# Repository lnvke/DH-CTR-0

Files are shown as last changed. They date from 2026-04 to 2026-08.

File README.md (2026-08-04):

# CTR-0
Cheaper Than aRduino is a custom devboard meant to be a cost-effective alternative my choice of the Arduino Nano series of devboard hobbyist microcontrollers. It is based of the same RP2040 microcontroller and will provide similar performance compared to its more costly counterpart, the Arduino Nano V3, which is the board I usually use for projects that require a microcontroller.


=======
## Roadmap
- finalize parts
  -finish footprints for any new parts
- pcb footprint, general size
  - placement/routing first pass
- cost optimization
- routing second pass
- final route optimization
- send gerbers to JLCPCB and order
- assemble
- done

## BOM links:

Capacitors:
0.1 uf https://www.digikey.com/en/products/detail/yageo/CC0402KRX7R7BB104/2103076
4.7 uf https://www.digikey.com/en/products/detail/yageo/CC0402MRX5R5BB475/5195139
10 uf https://www.digikey.com/en/products/detail/yageo/CC0603MRX5R5BB106/2833613
1 uf https://www.digikey.com/en/products/detail/yageo/CC0402KRX5R5BB105/2833744
15 pf https://www.digikey.com/en/products/detail/yageo/CC0402JRNPO9BN150/302751

Resistors:
5.1k https://www.digikey.com/en/products/detail/yageo/RC0402FR-075K1L/726624
27 https://www.digikey.com/en/products/detail/yageo/RC0402FR-0727RL/5280946
10k https://www.digikey.com/en/products/detail/yageo/RC0402FR-0710KL/726523
1k https://www.digikey.com/en/products/detail/yageo/RC0402FR-071KL/726513

Receptacles/Header Pins
THT 20h https://www.digikey.com/en/products/detail/sullins-connector-solutions/PRPC020SAAN-RC/2775234
THT 3h https://www.digikey.com/en/products/detail/sullins-connector-solutions/PRPC003SAAN-RC/2775251
USB4015 https://www.digikey.com/en/products/detail/gct/USB4105-GF-A/11198441

IC
TVS Diode https://www.digikey.com/en/products/detail/texas-instruments/TVS1400DRVR/8566097
NCP1117 https://www.digikey.com/en/products/detail/onsemi/NCP1117ST33T3G/1749063
Flash memory https://www.digikey.com/en/products/detail/macronix/MX25L12872FM2I-10G/10059507
RP2040 https://www.digikey.com/en/products/detail/raspberry-pi/SC0914-13/14306010
Crystal Resonator https://www.digikey.com/en/products/detail/abracon-llc/ABLS-12-000MHZ-B4-T/675654

Interface
SKRKAEE020 Push Button https://www.digikey.com/en/products/detail/alps-alpine/SKRKAEE020/19529176

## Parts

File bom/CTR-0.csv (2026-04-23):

Reference | Qty | Value | DNP | Exclude from BOM | Exclude from Board | Footprint | Datasheet
C1,C2 | 2 | 10u |  |  |  | Capacitor_SMD:C_0603_1608Metric
C3,C4 | 2 | 15p |  |  |  | Capacitor_SMD:C_0402_1005Metric
C5 | 1 | 5u |  |  |  | Capacitor_SMD:C_0402_1005Metric
C6,C15 | 2 | 1u |  |  |  | Capacitor_SMD:C_0402_1005Metric
C7,C8,C9,C10,C11,C12,C13,C14,C16,C17 | 10 | 0.1u |  |  |  | Capacitor_SMD:C_0402_1005Metric
C18 | 1 | 100n |  |  |  | Capacitor_SMD:C_0402_1005Metric
J1 | 1 | USB_C_Receptacle_USB2.0_14P |  |  |  | Connector_USB:USB_C_Receptacle_HRO_TYPE-C-31-M-12 | https://www.usb.org/sites/default/files/documents/usb_type-c.zip
J2,J3 | 2 | Conn_01x20 |  |  |  | Connector_PinHeader_2.54mm:PinHeader_1x20_P2.54mm_Vertical
J4 | 1 | Conn_01x03 |  |  |  | Connector_PinHeader_2.54mm:PinHeader_1x03_P2.54mm_Vertical
R1,R2 | 2 | 5.1k |  |  |  | Resistor_SMD:R_0402_1005Metric
R3,R7,R9 | 3 | 1k |  |  |  | Resistor_SMD:R_0402_1005Metric
R4,R5 | 2 | 27 |  |  |  | Resistor_SMD:R_0402_1005Metric
R6,R8 | 2 | 10k |  |  |  | Resistor_SMD:R_0402_1005Metric
SW1,SW2 | 2 | SW_Push |  |  |  | Button_Switch_SMD:SW_Push_SPST_NO_Alps_SKRK
U1 | 1 | RP2040 |  |  |  | Package_DFN_QFN:QFN-56-1EP_7x7mm_P0.4mm_EP3.2x3.2mm | https://datasheets.raspberrypi.com/rp2040/rp2040-datasheet.pdf
U2 | 1 | NCP1117-3.3_SOT223 |  |  |  | Package_TO_SOT_SMD:SOT-223-3_TabPin2 | http://www.onsemi.com/pub_link/Collateral/NCP1117-D.PDF
U3 | 1 | W25Q128JVS |  |  |  | Package_SO:SOIC-8_5.3x5.3mm_P1.27mm | https://www.winbond.com/resource-files/w25q128jv_dtr%20revc%2003272018%20plus.pdf
U4 | 1 | TVS1400DRV |  |  |  | Package_SON:WSON-6-1EP_2x2mm_P0.65mm_EP1x1.6mm | http://www.ti.com/lit/ds/symlink/tvs1400.pdf
Y1 | 1 | 12MHz |  |  |  | Crystal:Crystal_SMD_3225-4Pin_3.2x2.5mm

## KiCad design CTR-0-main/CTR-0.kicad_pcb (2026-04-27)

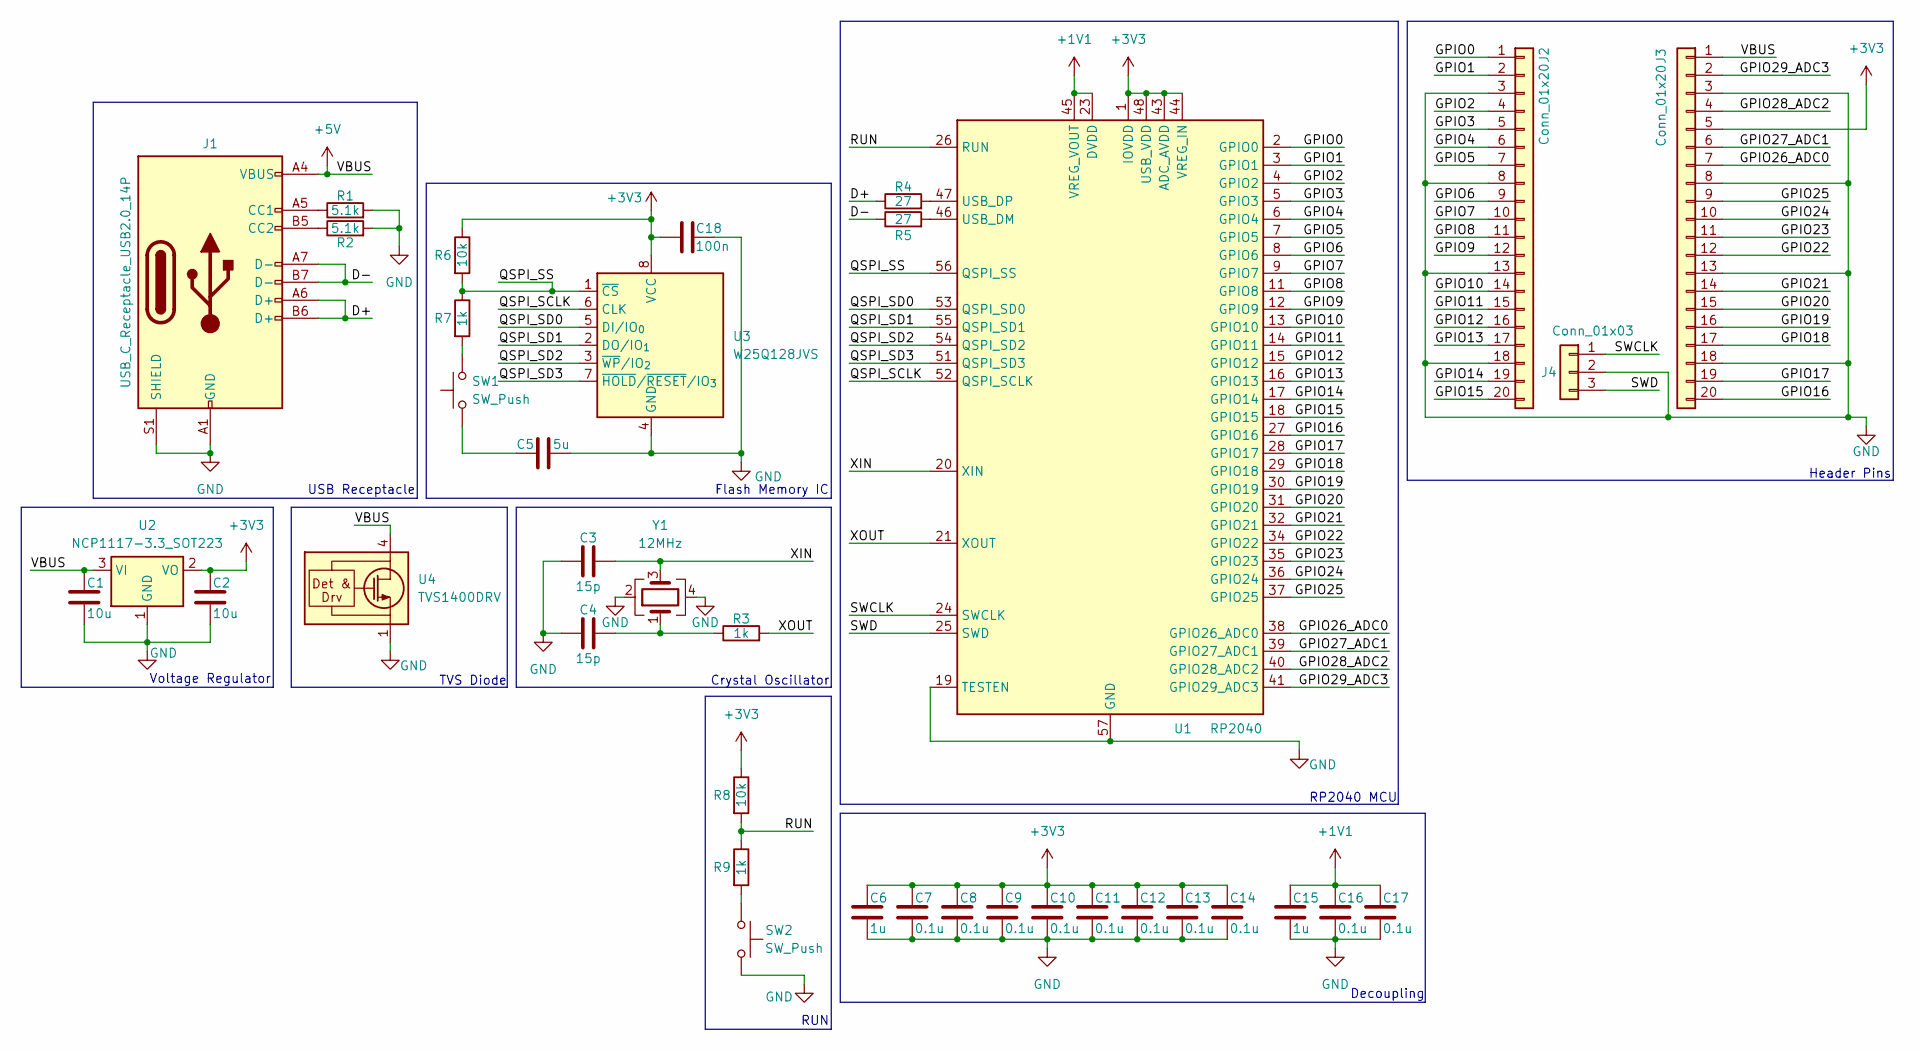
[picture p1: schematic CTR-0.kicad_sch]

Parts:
C1, C2: 10u; C_0603_1608Metric
C3, C4: 15p; C_0402_1005Metric
C5: 5u; C_0402_1005Metric
C6, C15: 1u; C_0402_1005Metric
C7, C8, C9, C10, C11, C12, C13, C14, C16, C17: 0.1u; C_0402_1005Metric
C18: 100n; C_0402_1005Metric
J1: USB_C_Receptacle_USB2.0_14P; USB_C_Receptacle_HRO_TYPE-C-31-M-12
J2, J3: Conn_01x20; PinHeader_1x20_P2.54mm_Vertical
J4: Conn_01x03; PinHeader_1x03_P2.54mm_Vertical
R1, R2: 5.1k; R_0402_1005Metric
R3, R7, R9: 1k; R_0402_1005Metric
R4, R5: 27; R_0402_1005Metric
R6, R8: 10k; R_0402_1005Metric
SW1, SW2: SW_Push; SW_Push_SPST_NO_Alps_SKRK
U1: RP2040; QFN-56-1EP_7x7mm_P0.4mm_EP3.2x3.2mm
U2: NCP1117-3.3_SOT223; SOT-223-3_TabPin2
U3: W25Q128JVS; SOIC-8_5.3x5.3mm_P1.27mm
U4: TVS1400DRV; WSON-6-1EP_2x2mm_P0.65mm_EP1x1.6mm
Y1: 12MHz; Crystal_SMD_3225-4Pin_3.2x2.5mm

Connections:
+1V1: C15.1, C16.1, C17.1, U1.23 (DVDD), U1.45 (VREG_VOUT), U1.50 (DVDD)
+3V3: C2.1, C6.1, C7.1, C8.1, C9.1, C10.1, C11.1, C12.1, C13.1, C14.1, C18.2, J3.5, R6.1, R8.1, U1.1 (IOVDD), U1.10 (IOVDD), U1.22 (IOVDD), U1.33 (IOVDD), U1.42 (IOVDD), U1.43 (ADC_AVDD), U1.44 (VREG_IN), U1.48 (USB_VDD), U1.49 (IOVDD), U2.2 (VO), U3.8 (VCC)
+5V: C1.1, J1.A4 (VBUS), J1.A9 (VBUS), J1.B4 (VBUS), J1.B9 (VBUS), J3.1, U2.3 (VI), U4.4 (IN), U4.5 (IN), U4.6 (IN)
/D+: J1.A6 (D+), J1.B6 (D+), R4.1
/D-: J1.A7 (D-), J1.B7 (D-), R5.1
/GPIO0: J2.1, U1.2 (GPIO0)
/GPIO1: J2.2, U1.3 (GPIO1)
/GPIO2: J2.4, U1.4 (GPIO2)
/GPIO3: J2.5, U1.5 (GPIO3)
/GPIO4: J2.6, U1.6 (GPIO4)
/GPIO5: J2.7, U1.7 (GPIO5)
/GPIO6: J2.9, U1.8 (GPIO6)
/GPIO7: J2.10, U1.9 (GPIO7)
/GPIO8: J2.11, U1.11 (GPIO8)
/GPIO9: J2.12, U1.12 (GPIO9)
/GPIO10: J2.14, U1.13 (GPIO10)
/GPIO11: J2.15, U1.14 (GPIO11)
/GPIO12: J2.16, U1.15 (GPIO12)
/GPIO13: J2.17, U1.16 (GPIO13)
/GPIO14: J2.19, U1.17 (GPIO14)
/GPIO15: J2.20, U1.18 (GPIO15)
/GPIO16: J3.20, U1.27 (GPIO16)
/GPIO17: J3.19, U1.28 (GPIO17)
/GPIO18: J3.17, U1.29 (GPIO18)
/GPIO19: J3.16, U1.30 (GPIO19)
/GPIO20: J3.15, U1.31 (GPIO20)
/GPIO21: J3.14, U1.32 (GPIO21)
/GPIO22: J3.12, U1.34 (GPIO22)
/GPIO23: J3.11, U1.35 (GPIO23)
/GPIO24: J3.10, U1.36 (GPIO24)
/GPIO25: J3.9, U1.37 (GPIO25)
/GPIO26_ADC0: J3.7, U1.38 (GPIO26_ADC0)
/GPIO27_ADC1: J3.6, U1.39 (GPIO27_ADC1)
/GPIO28_ADC2: J3.4, U1.40 (GPIO28_ADC2)
/GPIO29_ADC3: J3.2, U1.41 (GPIO29_ADC3)
/QSPI_SCLK: U1.52 (QSPI_SCLK), U3.6 (CLK)
/QSPI_SD0: U1.53 (QSPI_SD0), U3.5 (DI/IO_{0})
/QSPI_SD1: U1.55 (QSPI_SD1), U3.2 (DO/IO_{1})
/QSPI_SD2: U1.54 (QSPI_SD2), U3.3 (~WP/IO_{2})
/QSPI_SD3: U1.51 (QSPI_SD3), U3.7 (~HOLD/~RESET/IO_{3})
/QSPI_SS: R6.2, R7.1, U1.56 (QSPI_SS), U3.1 (~CS)
/RUN: R8.2, R9.1, U1.26 (RUN)
/SWCLK: J4.1, U1.24 (SWCLK)
/SWD: J4.3, U1.25 (SWD)
/XIN: C3.2, U1.20 (XIN), Y1.3
/XOUT: R3.2, U1.21 (XOUT)
GND: C1.2, C2.2, C3.1, C4.1, C5.1, C6.2, C7.2, C8.2, C9.2, C10.2, C11.2, C12.2, C13.2, C14.2, C15.2, C16.2, C17.2, C18.1, J1.A1 (GND), J1.A12 (GND), J1.B1 (GND), J1.B12 (GND), J1.S1 (SHIELD), J2.3, J2.8, J2.13, J2.18, J3.3, J3.8, J3.13, J3.18, J4.2, R1.2, R2.2, SW2.1, U1.19 (TESTEN), U1.57 (GND), U2.1 (GND), U3.4 (GND), U4.1 (GND), U4.2 (GND), U4.3 (GND), U4.7 (GND), Y1.2, Y1.4
unnamed: C4.2, R3.1, Y1.1
unnamed: C5.2, SW1.1
unnamed: J1.A5 (CC1), R1.1
unnamed: J1.B5 (CC2), R2.1
unnamed: R7.2, SW1.2
unnamed: R9.2, SW2.2
unnamed: R5.2, U1.46 (USB_DM)
unnamed: R4.2, U1.47 (USB_DP)

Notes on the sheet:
RP2040 MCU
Flash Memory IC
Crystal Oscillator
Decoupling
RUN
TVS Diode
Voltage Regulator
USB Receptacle
Header Pins

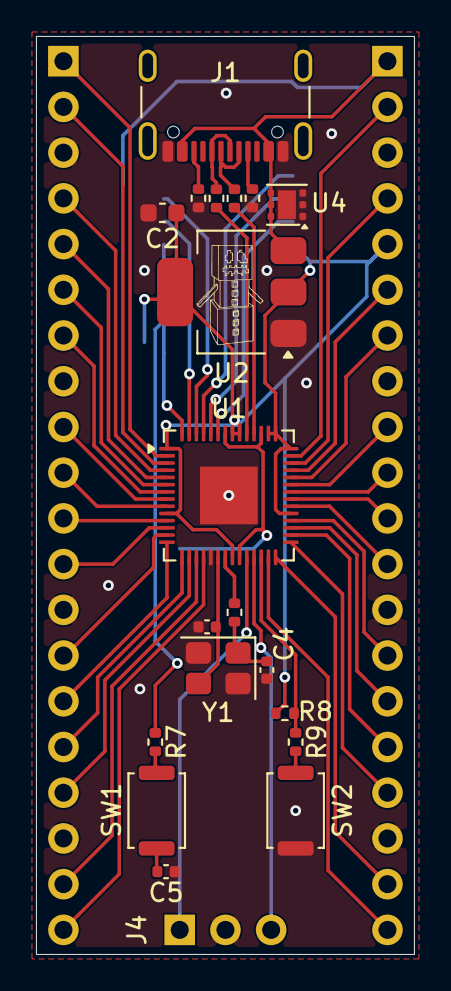
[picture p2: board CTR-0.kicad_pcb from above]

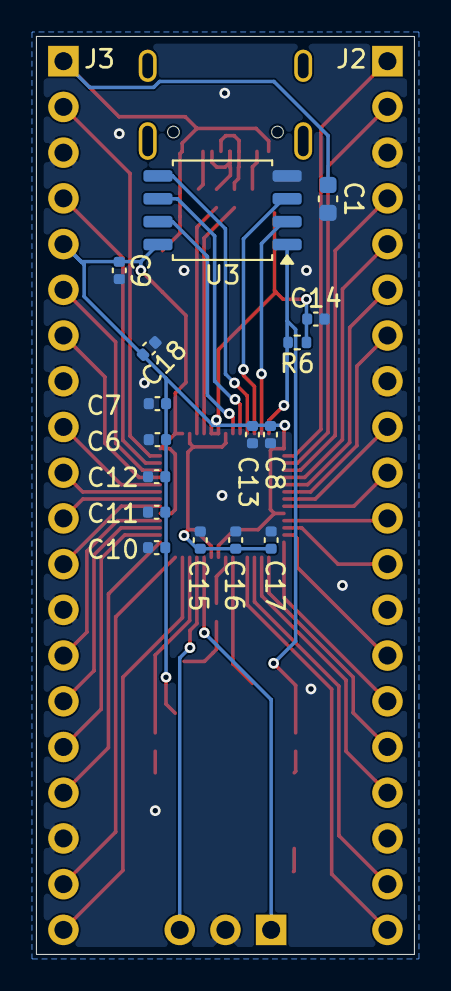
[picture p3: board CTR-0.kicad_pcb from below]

Board: 2 copper layers, 21.0 x 51.0 mm, 38 parts (18 on the bottom side), 55 nets.

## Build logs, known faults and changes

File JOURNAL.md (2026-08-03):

<!--
  This journal is auto generated by Stasis.
-->

# 4/24/2026 6 PM - Building my BOM

_Time spent: 2.5h_

When building my BOM, I realized that the previous USB footprint was exclusive to JLCPCB assembly and not available on Digikey.

I replaced it with a more conventional USB footprint.


In a similar vein, my 15MHz crystal was unsuitable for the RP2040, which requires a 12MHz crystal. I then spent a very long time looking for a wiring diagram for the ABM8-12.000MHZ-B2-T, but it turned out that it was using the same package anyways, so I ended up just renaming my crystal in my schematic.


The flash memory IC W25Q128JVS was out of stock, so I replaced it with the functionally similar MX25L12872FM2I-10G thanks to its similar price point and identical footprint. 

From here, I spent another hour organizing and double-checking my Digikey order.




# 4/23/2026 11 PM - DRC fixes

_Time spent: 1h_

In my very final pass, I cleaned up all the DRC errors to see this.



The exclusions were all edited footprints that were not matching library so those dont count. 

First, I edited all silkscreen text to be within the board.





Then, I went and edited the two 1x20 connectors, the 1x3, and the USB receptacle to remove edge cut violations.

Initially, I also removed the RP2040 silkscreen graphics, but I later put them back for ease of assembly, realizing F.Fab is not printed.





# 4/13/2026 12 PM - 3rd pass pt.2 (FINAL)

_Time spent: 4h_

Decoupling capacitors are now on the board.


I spent around an hour fixing library errors as well as clearances because I changed my snap grid preference halfway through this project.




Because of the size constraints, I was left with some unconnected islands in my ground pour. In the DRC, this shows as unconnected planes, but very rarely will Kicad actually tell you where this disconnect is, and between what zones. I spent around 2-3 hours re-pouring and trying to change settings to get rid of my islands, as well as manually routing some of my grounds. This was very time consuming and I really wish Kicad would highlight or otherwise put a marker on the specific zones where the nets are unconnected. In the end, I kept the islands, but put vias through the ground planes to connect them.







# 4/9/2026 8 PM - 3rd pass pt.1

_Time spent: 2.5h_

In each pass of my routing, I focus on different things. My first pass is focused on connections and how they translate onto the physical pcb. The second pass was more focused on optimizing those connections, and this final pass intends to optimize positioning in order to achieve better connections. 

This image is the initial 3rd pass connection routing.


The only routes I need to do from here are the decoupling capacitors.




# 4/9/2026 7 PM - minor schematic fixes

_Time spent: 1h_

After spending some time polishing my 2nd pass and getting ready to wipe it for a 3rd, I realized that I lacked a run button to go with my flash button. From here I quickly created a button for the RUN pin and rerouted the 2nd pass to include it.







# 4/3/2026 9 PM - Reroute 2nd pass pt.3

_Time spent: 3.5h_

The finishing touches for my 2nd reroute included general route polishing which included things like cleaning up vias and removing unnecessary bends. Moreover, small placement adjustments were made to ensure the route was clean, and I figured out the placement for the decoupling capacitors



My next steps are to run this through DRC, final fixes, then delete and re-route for 3rd pass with a focus on placement.




# 4/3/2026 9 PM - Reroute 2nd pass pt.2

_Time spent: 3h_

For my 2nd pass, re-routing was my primary directive, and managing my route for the component with the most pinouts (the microcontroller) was certainly the most challenging and of most importance.

Managing via placement and clearance were initially a problem, which is why I started with microvias, but upon further experimentation, normal vias were possible without compromising signal integrity. I also completely eliminated all GPIO vias, which were also a potential source of issues for signal integrity. All in all, i tried to avoid placing vias on data transmit and receive, clock lines, and GPIO pins, which proved to be an issue for the rest of my PCB.





# 4/2/2026 10 PM - Reroute 2nd pass pt,1

_Time spent: 3h_

In this session, I experimented with microvia and blind/buried vias on my pcb as shown here.

I almost completely routed the entire pcb with microvias until I realized that the width of the copper around the via actually changes in diameter, which can mess with signals. I went down a rather lengthy and time-consuming tangential study on signal integrity and how pcb designers try to maintain it.





# 3/28/2026 8 PM - Redo of First Pass

_Time spent: 4.5h_

Following the loss of my schematic, I spent around 4 hours re-placing, re-routing, and re-doing everything. Not much to say. Lots of errors, but this is a first pass, just to get a feeling of about how im going to place things.











# 3/28/2026 7 PM - Recovering Lost Data

_Time spent: 2h_

My kicad schematic did not save, and so by extension, parts of my PCB disappeared. I spent around an hour trying to recover my files by looking through my github commits and my local commits. Realizing that I probably didn't save, I went and re-did the schematic with some minor changes. From there, I replaced footprints and re-researched parts such as my crystal oscillator, which I realized needed a lower farad capacitor.








# 3/26/2026 2 PM - More fixes

_Time spent: 4.5h_

After finishing my schematic, I realized some of my footprints were wrong, so I went back and found compatible replacements. 

This meant I had to re-do some of the PCB routing that I did earlier, which was looking to be very time-consuming. From here, I was able to re-do my first pass of placement/routing.


Additionally, I added a TVS diode to the VBUS 5V for safety reasons, incase of a backflow or any sort of surge.



I still havent figured out how to place the decoupling capacitors around the mcu, however, that will be decided in my 2nd-3rd pass.




# 3/25/2026 4 AM - Polishing schematic, final wiring changes

_Time spent: 3h_

I spent a lengthy debugging session in the DRC in Kicad, and went over a second pass of the schematic.

In a previous journal, I mentioned that the GPIO25 pin had no corresponding header due to the fact that the RUN pin was unnecessarily tied to a header pin, when instead GPIO25 could be tied to that pin.


I then tied this RUN pin directly to a button instead of to the header pin as per the guide. I did this with a few more pins, rearranging the header pinout as I went.
I also fixed the flash memory IC and made the schematic a lot easier to read.






# 3/24/2026 1 AM - Quick roadmap

_Time spent: 0.5h_

I spent 10 minutes creating a roadmap for myself on GitHub in the readme. 
improvements and more specific stuff to come, but just something to remind me of what to do.


Besides this, I have fixed some errors in the schematic after running the ERC. I noticed that the devboard itself lacked a connection to the RUN pin as well as having an extra unused GPIO25 pin.





# 3/24/2026 12 AM - Finished Base Schematic

_Time spent: 4.5h_

Following the guide, I finished the schematic for the RP2040 devboard. I was confused about the various resistances used for pullup resistors, and took some time researching the specific use for them. Likewise, I was also confused about decoupling capacitors in the same way, and so I spent some time researching the purpose and how the value affects the performance of the signal.

A small side-tangent I took during my research was on the various protocols used by electronic components to communicate with each other, such as serial TX/RX, I2C, and SPI; I also researched display protocols such as HDMI and the various types of MIPI display serial interfaces.

Additionally, I also spent a good amount of time in the RP2040 datasheet to fully understand its clock rate and its voltage ratings to finalize the decision on the crystal oscillator. Most notably, the 15 picofarad capacitors on the oscillator circuit made me wonder about the oscillation rate and its delay, because after I learned about debounce capacitors I began to apply my knowledge here. It turns out that the capacitors are placed with special capacitance to ensure a perfect high and low signal, as they provide a delay such that the crystal oscillates itself exactly 180 degrees out of phase.

From here, I neeed to decide the specific parts that I would use, the crystal oscillator being one of them. Likewise, I would also have to find my own USB-C receptacle that fit the footprint required. 








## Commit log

2026-03-23 uploaded .pro file for further work
    [CTR-0.kicad_pcb, CTR-0.kicad_sch]
2026-03-28 fixed lost data
    remade schematic, re-applied footprints, and rerouted first pass of pcb
    [CTR-0.kicad_pcb, CTR-0.kicad_sch]
2026-04-02 Delete CTR-0 directory
    false directory
    [CTR-0.kicad_pcb, CTR-0.kicad_sch]
2026-04-09 3rd pass
    repositioned, made full use of board, optimized routing
    [CTR-0.kicad_pcb, CTR-0.kicad_sch, pass2.kicad_pcb]
2026-04-19 Add files via upload
    fixed drc gnd net
    [CTR-0.kicad_pcb, CTR-0.kicad_sch]
2026-04-23 fix
    minor fixes to last push
    [CTR-0.kicad_pcb]
2026-04-23 removed excess files
    [CTR-0.csv, CTR-0.kicad_pcb, CTR-0.kicad_sch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]
2026-04-24 organization
    changed file location for bom
    [CTR-0.csv]
2026-04-24 add
    gerber
    [CTR-0-B_Cu.gbr, CTR-0-B_Mask.gbr, CTR-0-B_Paste.gbr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]
2026-04-24 update
    fixed gerbers
    [CTR-0-B_Cu.gbr, CTR-0-B_Mask.gbr, CTR-0-B_Paste.gbr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]
2026-04-25 fix
    silkscreen
    [CTR-0.kicad_pcb]
2026-04-27 edit
    i lowkey dont know what
    [CTR-0.kicad_pcb]
